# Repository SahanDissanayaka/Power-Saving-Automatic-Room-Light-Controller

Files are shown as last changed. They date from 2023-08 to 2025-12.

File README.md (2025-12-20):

# Power Saving Automatic Light Controller

## Project Overview
The Power Saving Automatic Light Controller is designed to automatically control lighting to conserve energy. This system uses motion detection to operate lights only when necessary, thus enhancing efficiency and reducing electricity consumption.

## Team Members
- **Sahan Dissanayaka**
- **Sadaru Liyanaarachchi**
- **Pasindu Nimsara**
- **Dilshan Nuwantha**

## Contents
1. [Specifications](#specifications)
2. [Circuit Design](#circuit-design)
3. [Enclosure Design](#enclosure-design)
4. [Budget Proposal](#budget-proposal)
5. [Finalized Product](#finalized-product)
6. [Contributions](#contributions)

## Specifications
### Transmitter Part

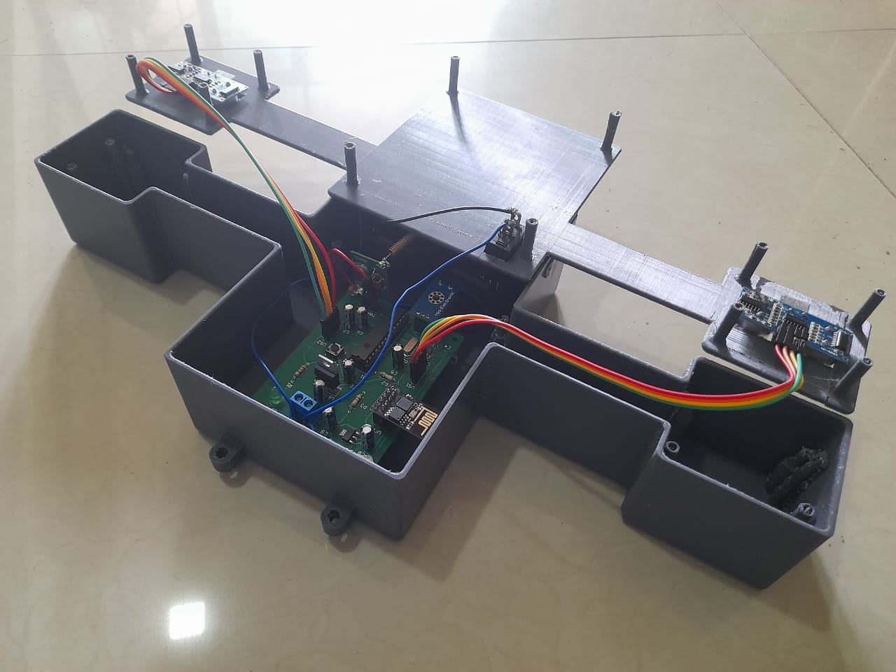
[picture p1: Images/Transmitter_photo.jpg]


- Controlled by ATMEGA328PU micro-controller
- Motion detection using two ultrasonic sensors
- Communication with receiver using 433MHz transmitter
- Wi-Fi updates via ESP8266 module
- Powered by two 3.7V rechargeable batteries

### Receiver Part

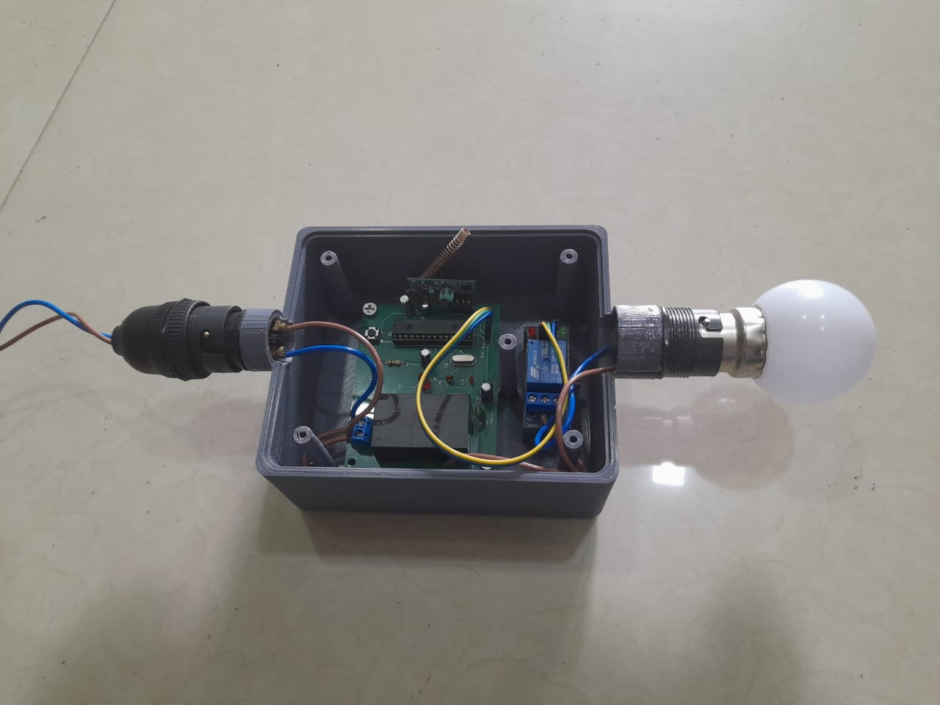
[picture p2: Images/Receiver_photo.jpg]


- Controlled by ATMEGA328PU micro-controller
- Communication with transmitter using 433MHz receiver
- Power supply: 230V AC to 5V DC step-down transformer

## Circuit Design
### Transmitter Side
- Ultrasonic sensors for motion detection
- 433 MHz transmitter for wireless communication
- ESP8266 wifi module for Wi-Fi connectivity

### Receiver Side
- 433 MHz receiver for wireless communication
- Step-down transformer for power supply

## Enclosure Design
### Transmitter Enclosure
- Designed for portability and durability
- Protects internal components from environmental factors

### Receiver Enclosure
- Designed for fixed installation
- Ensures safety and longevity of internal components

## Finalized Product
- **Transmitter Part**: Efficiently detects motion and transmits data wirelessly.
- **Receiver Part**: Receives data and controls lighting based on the received information.

## Thank You
Thank you for reviewing our project. We appreciate your interest and support.

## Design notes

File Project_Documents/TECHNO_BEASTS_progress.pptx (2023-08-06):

## Power Saving Automatic Light Controller

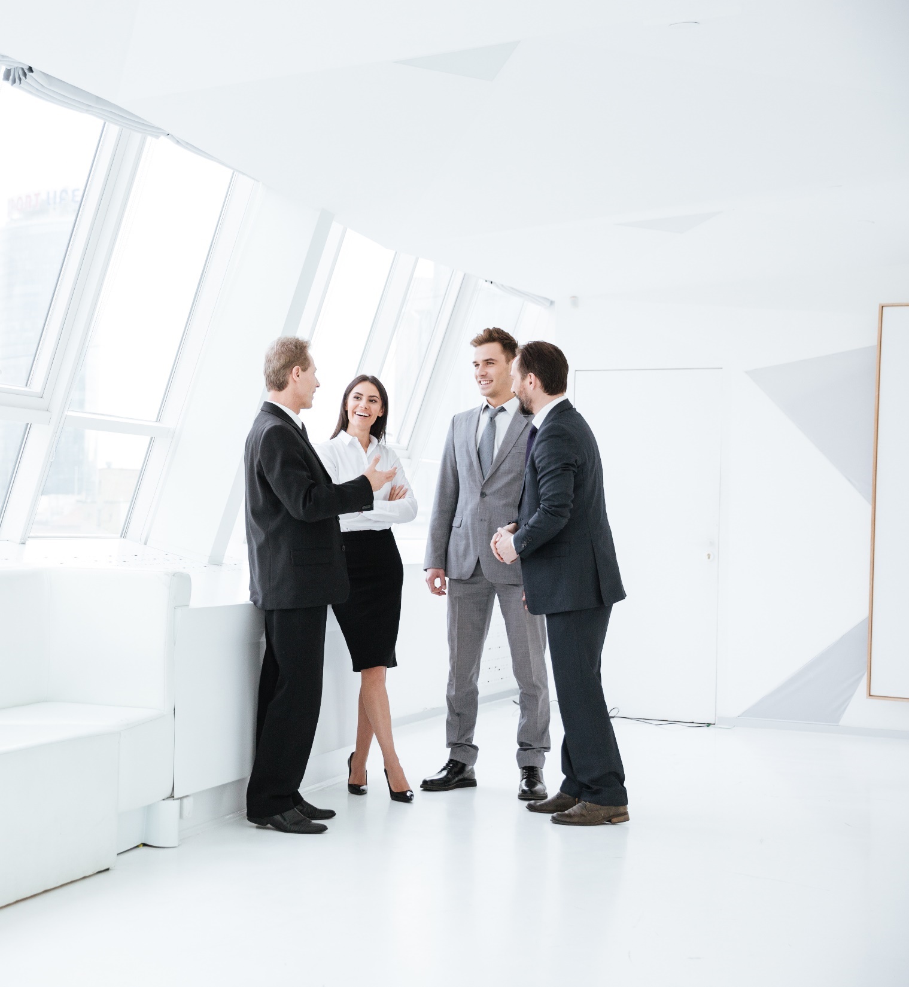
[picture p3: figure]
Group of people talking
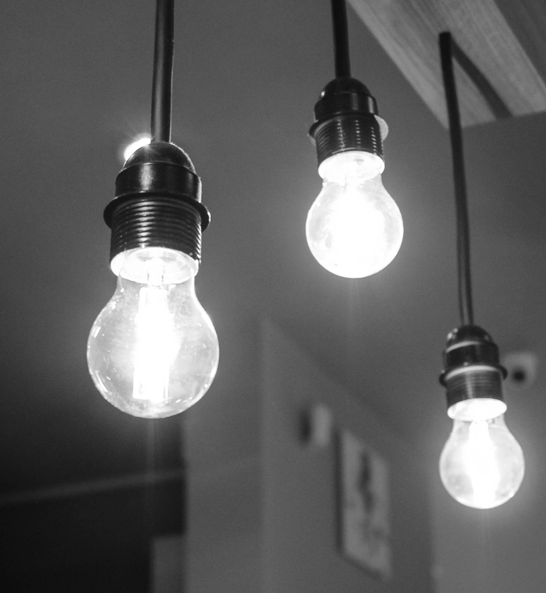
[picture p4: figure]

Team Techno beast

- 210141U – Dissanayaka D.M.S.P.
- 210341H – Liyanaarachchi L.A.S
- 210303U – Kulasingham P.N
- 210705E – Wickramasingha M.P.D.N

## Content

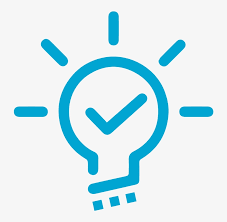
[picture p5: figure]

Problem & Solution
Problem
Survey Results
Solution
Technical Feasibility
Resource Requirements
Performance Targets
Technical Risks
Testing and Evaluation
Product Architecture
Sensor part
Light bulb part
Sketches
Initial Sketch
Finalized Sketch
Marketing & Sales
Marketing
Sales
After-sale Service
Bill of quantities
Summery of expenditure
Quantities

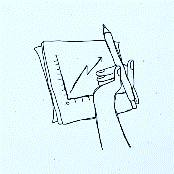
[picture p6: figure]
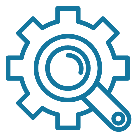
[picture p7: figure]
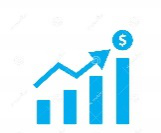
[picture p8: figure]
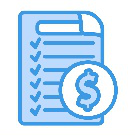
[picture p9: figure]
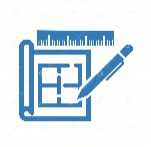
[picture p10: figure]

## Problem & Solution

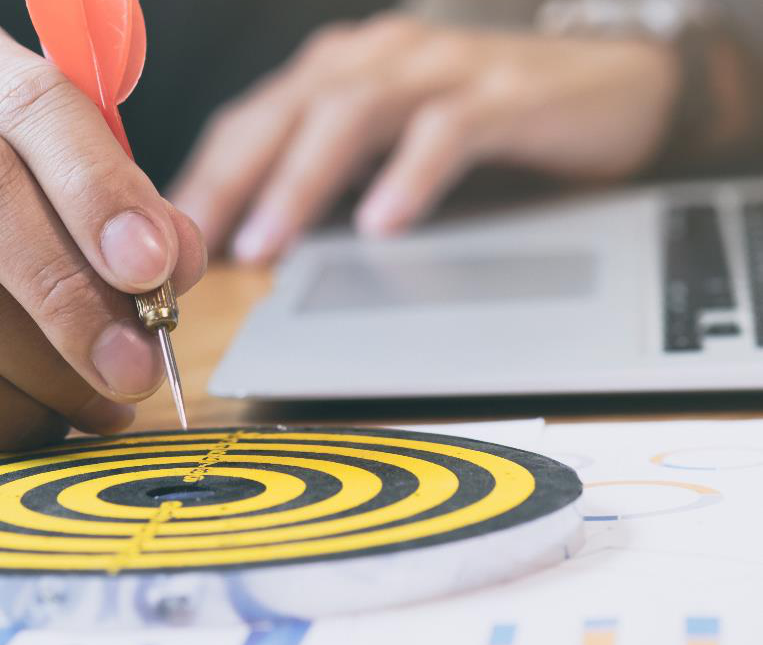
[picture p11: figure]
A picture containing object that represents mission, goal

- Do you forget to switch off the bulb when they are leaving the place?
- Have you any children or disable member in your family which can’t turn off lights.
- The development of this project is a timely and essential project with the potential to solve not only that but also extra too many problems.

## Survey Results

- We got 198 responses from the survey.
- We targeted a sample in society with all types of people covered.
- We could find many valuable facts and identify what people need.

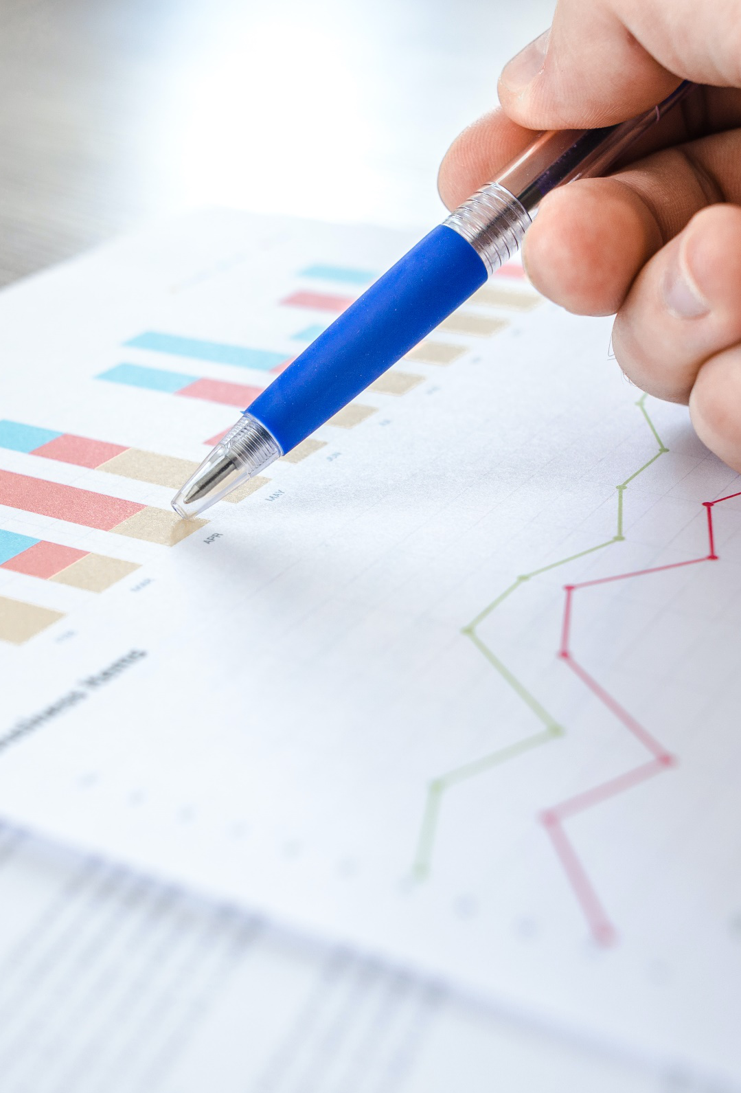
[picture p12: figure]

## Survey Results

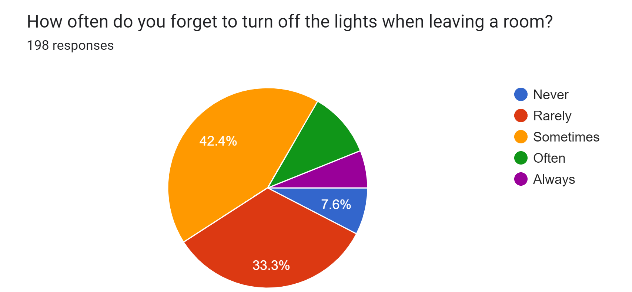
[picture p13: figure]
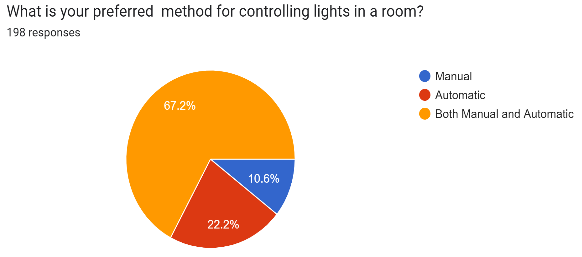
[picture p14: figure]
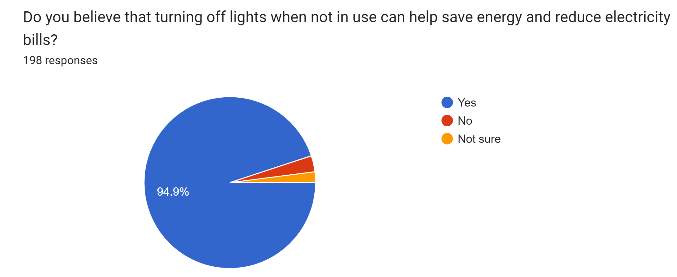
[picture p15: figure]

## Survey Results

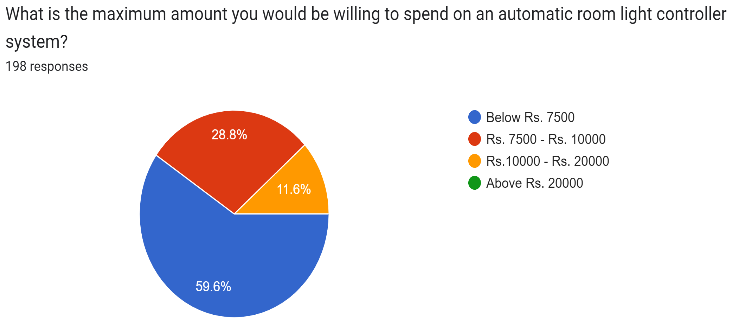
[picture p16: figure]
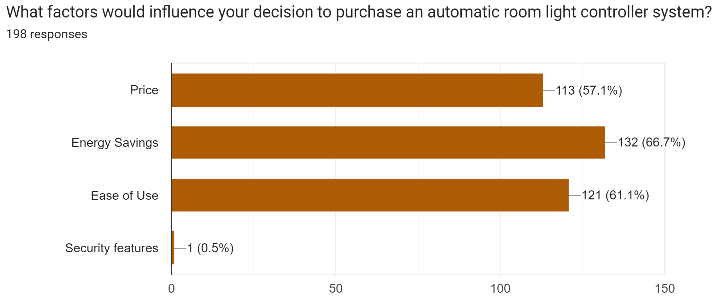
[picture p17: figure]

## Technical Feasibility

Resource Requirements

- Include light bulbs, sensors, PCBs, power-supplying methods, and transmitters.
- The software requirements include firmware for the microcontrollers, communication protocols.
- The software that we needed is Arduino, Solid Works, Altium, etc.

Performance Targets

- Based on industry standards.
- The system will be designed to turn on the lights automatically when someone enters the room and turn them off when they leave, thereby conserving energy.
- The main thing is when people enter the room more than one, the light will only be off if all of them left from the room.

## Technical Feasibility

Technical Risks

- mainly related to hardware and software compatibility.
- We have addressed these risks by carefully selecting the components and developing software components that are compatible with each other.
- tested the system thoroughly in a controlled environment and have identified and resolved any issues.

Testing and Evaluation

- Tested using a combination of manual testing and automated testing tools using simulations and hardware components.
- The tests will be conducted in a controlled environment simulating different scenarios and conditions.
- The evaluation criteria will be based on the system's energy efficiency, response time, reliability, and accuracy.

## Product Architecture

Power Supply (Battery)

7805 Regulator

input

Microprocessor

output

input

Ultrasonic

Transmitter

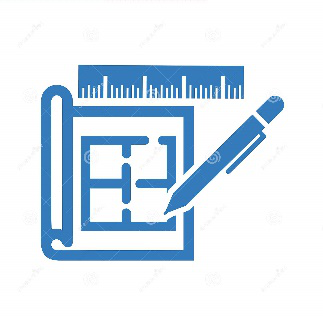
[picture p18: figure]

Receiver

Main Power 230V

Microprocessor

input

Relay Module

Hi-Link Transformer

input

output

Bulb

## Initial and Finalized Sketches

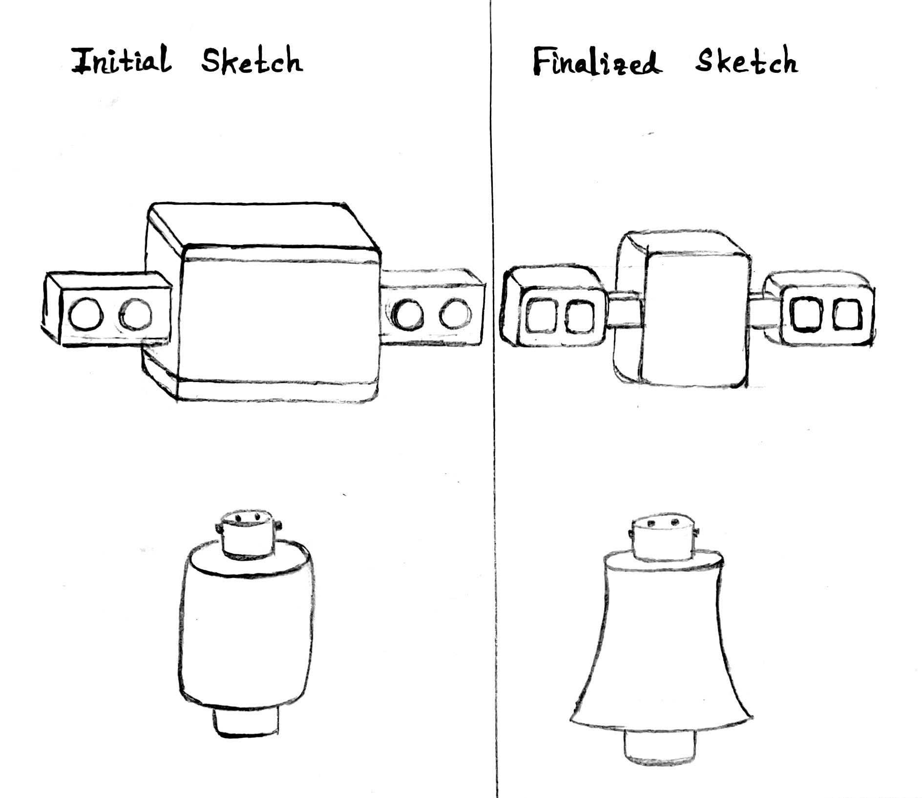
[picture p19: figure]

## Marketing, Sales, and After-Sale Service Considerations

- Marketing

- Mostly middle age people will be targeted because they are interested in technology and easy ways to do something.
- Use social media platforms and digital marketing strategies to reach a wider audience and it’s better to advertise on TV is useful because most people can be caught.
- Partner with home automation companies and energy-efficient solution providers to increase exposure and reach new customers.
- Attend trade shows and exhibitions to showcase the product and generate interest.

- Sales

- Develop a sales strategy to ensure the automatic light bulb system is priced competitively. Create a sales team to promote and sell the product to potential customers.
- Offer discounts or prizes to make the product more attractive.
- Provide incentives to retailers and distributors to promote the product.
- Develop a sales forecast to project revenue and sales targets. It is a back-office task but more important to succeed in the purpose.

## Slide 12

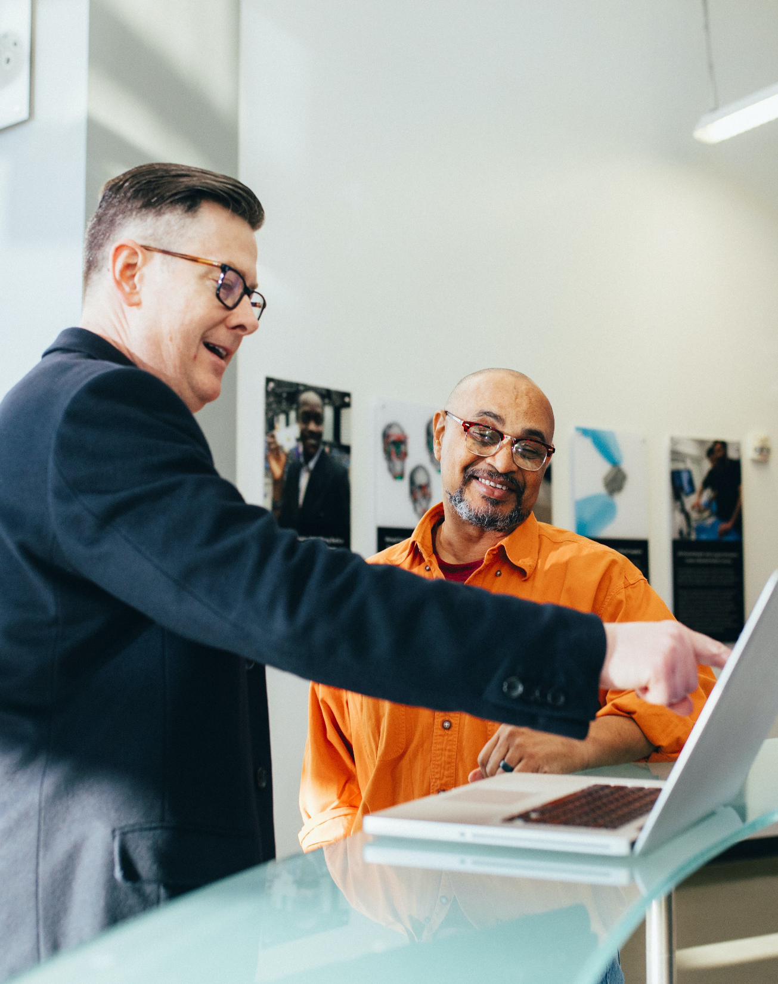
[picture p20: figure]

- After-Sale Service

- Offer a warranty and maintenance plan for the automatic light bulb system. But pay attention to the period and conditions.
- Provide customer support via email, phone, or online chat to answer questions and troubleshoot issues.
- Develop a customer feedback mechanism to monitor satisfaction levels and improve the product. I will be really important to the market also.
- Provide training and educational resources for customers to ensure they get the most out of the product.
- Develop a repair and replacement plan to address any issues that may arise.

## Bill of Quantities

Product | Price
Atmel ATMEGA328-PU microcontroller(2) | Rs. 2800.00
HC-SR04 4Pin Ultrasonic Sensor Module(2) | Rs. 640.00
433MHz Wireless RF Transmitter Receiver Module(1) | Rs. 340.00
5VDC 1 way 1 Channel Relay Module(1) | Rs. 180.00
L7805CV 5V Voltage Regulator(1) | Rs. 50.00
Tactile Push bottom 6×6×4 mm (2) | Rs. 20.00
16MHz Crystal Oscillator(2) | Rs. 80.00
220-ohm 2W resistor pack Carbon Film THT 5% (approx.5pcs)(1) | Rs. 60.00

Product | Price
10k ½ W Resistor Pack Carbon Film THT 5% (Approx.20pcs) | Rs.60.00
22pF Ceramic Capacitor THT(4) | Rs. 20.00
10uF 16V Electrolytic Capacitor THT(3) | Rs. 30.00
1nF 16V Electrolytic Capacitor THT(2) | Rs. 10.00
2-way Mini JST 2.0 PH Connector Wire Micro bit(2) | Rs. 40.00
Hi-Link HLK-5M05 220VAC to 5VDC 5W Step-Down Power Supply Module(1) | Rs. 1350.00
28-pin Normal IC Base 2.5 mm (HE0021)(2) | Rs. 40.00
433MHz Helical Antenna(2) | Rs. 230.00

Total | Rs. 5945.00

## Thank you!

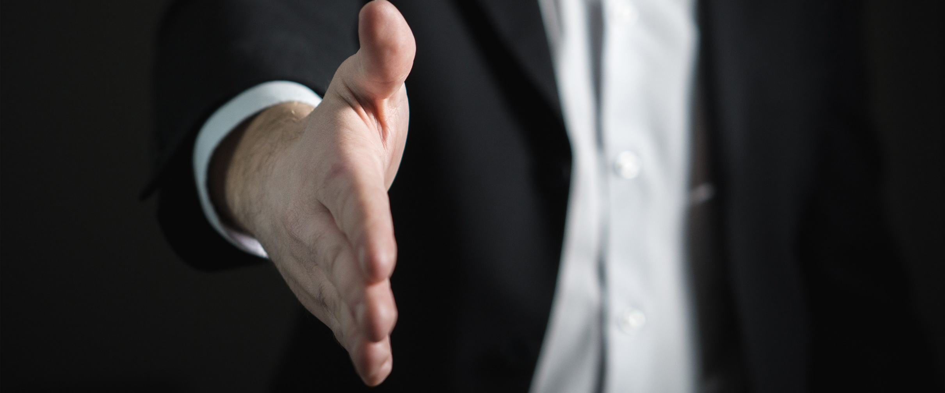
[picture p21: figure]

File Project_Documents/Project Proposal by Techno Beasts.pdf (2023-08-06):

# EN1190 Engineering Design Project

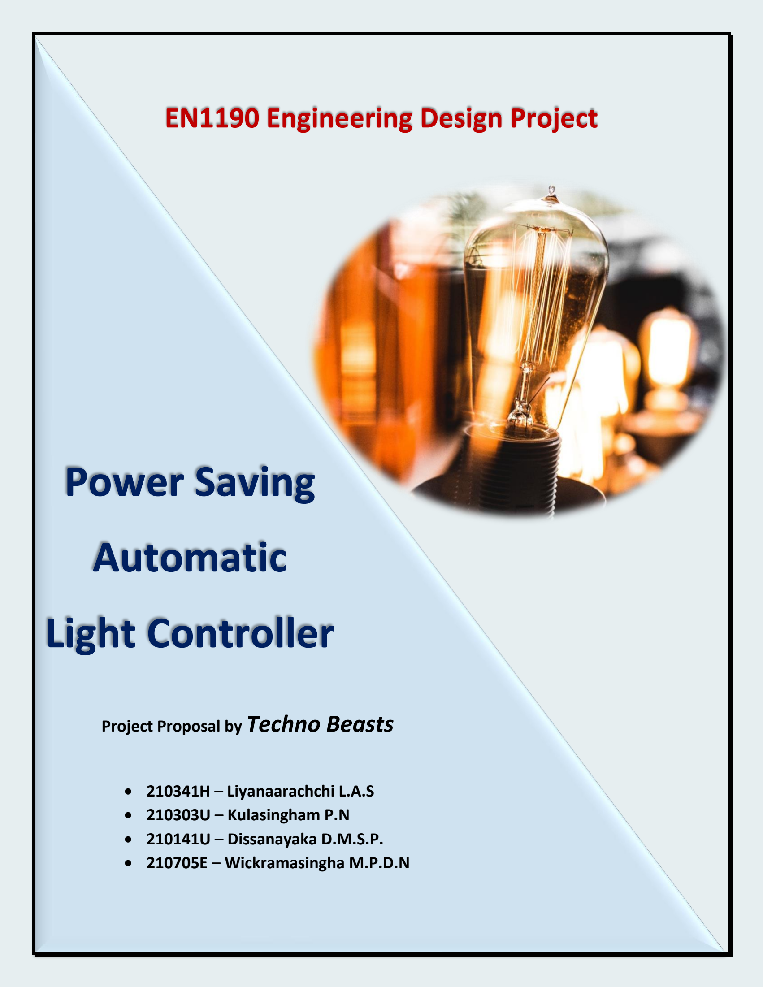
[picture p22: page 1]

Project Proposal by Techno Beasts

- 210341H – Liyanaarachchi L.A.S
- 210303U – Kulasingham P.N
- 210141U – Dissanayaka D.M.S.P.
- 210705E – Wickramasingha M.P.D.N

# Power Saving

# Automatic

# Light Controller

## Introduction

## Identified Problem

## Solutions

❖ In this project we mainly focus to build an automatic room light controller to save the power by counting the number of people who entering to the room and getting
out from the room. Also, we hope to bring some convenience to users by reducing their time they spend switching the ON and OFF bulb.

❖ Energy Waste: Traditional light switches can lead to unnecessary energy waste, as people often forget to turn off the lights when leaving a room. It can cause to increasing energy waste and electricity bills.
❖ Convenience: It might be inconvenient to have to manually turn lights on and off every time we enter or leave a place.
❖ Accessibility: Disabled people may face challenges in accessing and operating light switches, which can limit their independence and make it difficult to navigate the surroundings.
❖ Safety: Forgetting to turn off a light before leaving a room can pose safety risks, such as the risk of fire hazards or damage to property.

❖ Energy Efficiency: Our automatic room light controller can help reduce energy waste by turning off the lights when no one is present in the room. This can lead to a decrease in energy consumption and lower electricity bills.
❖ Convenience: By automatically turning on the lights when someone enters the room, automated light controller may give a more smooth and convenient lighting experience, removing the need for manual switches.
❖ Accessibility: Our light controller can help to increase accessibility for disabled people who may have difficulties with accessing or manipulating light switches. This project can make it easy for everyone to use the lighting by automating the process of turning lights on and off.
❖ Safety: Light controller can help to protect the property without any damage by turning off the lights automatically when no one is in the room.
❖ Cost Savings: Our design can help to reduce electricity bills by lowering energy consumption. It helps people to stabilize financial. This can lead to long-term cost savings for homeowners or businesses.

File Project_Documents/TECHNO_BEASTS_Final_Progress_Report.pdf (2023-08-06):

## Department of Electronic and Telecommunication Engineering University of Moratuwa EN1190 – Engineering Design Project

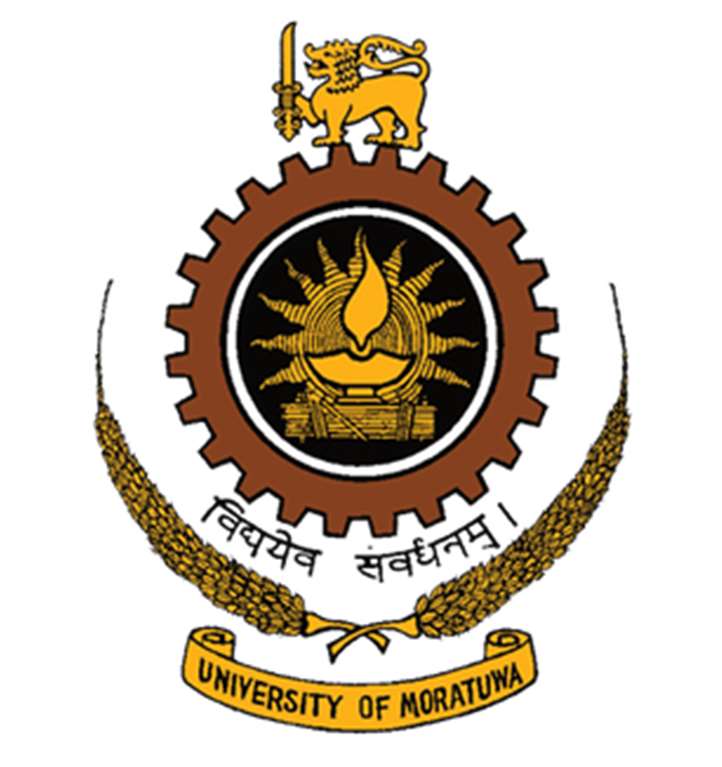
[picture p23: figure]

### Power Saving Automatic Light Controller

Group Members
- 210141U – Dissanayaka D.M.S.P.
- 210341H – Liyanaarachchi L.A.S
- 210303U – Kulasingham P.N
- 210705E – Wickramasingha M.P.D.N

1

## Table of Contents

2

## Abstract

Our design, a power-saving automatic light controller, is a device that automatically turns lights on and off based on the presence or absence of people in a room or area. The controller uses sensors such as ultrasonic sensors to detect human movements and switch the lights on and off accordingly. By using this type of controller, energy consumption is reduced since lights are only activated when needed. Additionally, the controller can be programmed to adjust the brightness level of the lights, further reducing energy consumption. The power-saving automatic light controller is a practical and cost-effective solution for reducing energy consumption and improving the efficiency of lighting systems and which is more helpful for disabled people. In this report, we consider what people think about our product through the survey. Furthermore, the technical feasibility and budget of the product are also included in this report.

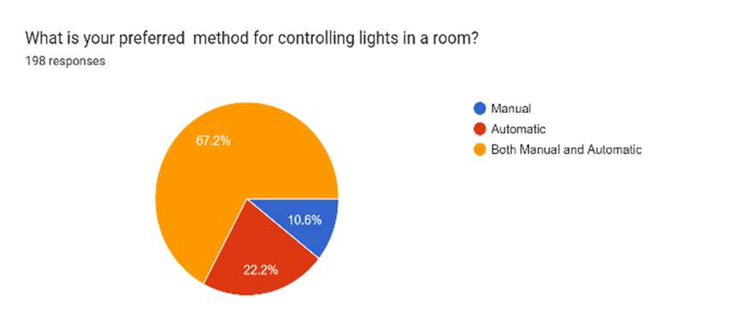
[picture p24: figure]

3

## Problem & Solution

In day-to-day life, most people forget to switch off the bulb when they are leaving the place. It may cause energy waste. Therefore, electricity consumption will be increased. In these days, if electricity consumption is increased then the electricity bill will be increased. Our income got wasted because of that. By implementing an automated lighting solution that turns off lights when a room is unoccupied, we can reduce energy waste and promote a more sustainable future. Hence, we should save energy. For that at least we can switch off the bulbs when we leave the place. So, we can introduce an automatic system for switching off the bulbs. And, if we forget to turn off the light bulbs then it may cause safety risks such as fire hazards or property damage.
In our society, we meet disabled people. They are suffering because they cannot do their work individually. As an example, people who are using wheelchairs cannot switch on the lights in the room without others' help. Such as most disabled people suffer from these stuffs. So, these people face different kinds of problems such as accessing and operating light switches. So, we are thinking to introduce an automatic system for lighting the bulbs. It helps to increase disabled people’s independence. Therefore, they can enter a room without others' help.

## Survey Summary

We did a small survey on our project. Some of the responses are shown below.
Most responders sometimes forget to turn off the lights when they leave the room. The least number of responders turn off the lights when leaving a room.

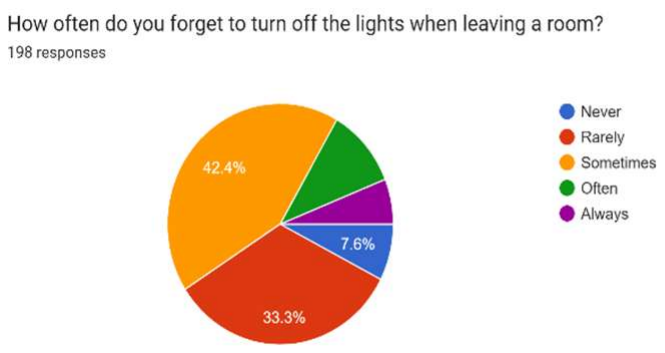
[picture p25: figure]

Most people like to control lights in both manual and automatic manners. Minimum responders prefer to turn on and off lights manually. So, this will help to improve our product in both manual and automatic.
When individuals with disabilities or children use this product, we can guarantee their safety and they can increase their independence. As the responses of the responders all of them said that disabled people can improve their safety.

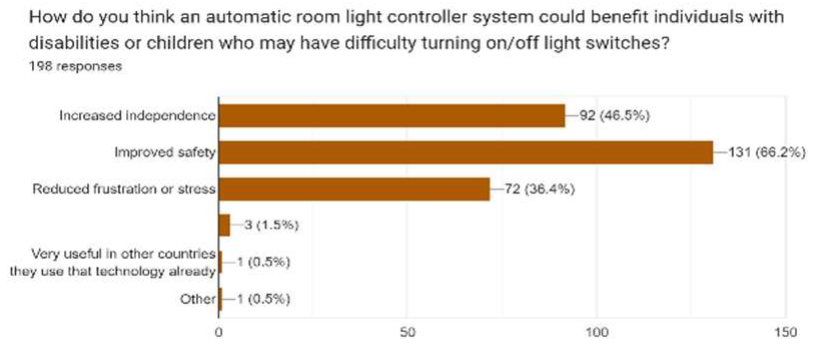
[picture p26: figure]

Most of the respondents prefer to buy our product by spending below Rs. 7500. And 57 responders like to spend between Rs. 7500 – Rs. 10000 to buy this product. Furthermore, some of them also prefer to spend between Rs.1000-Rs.2000 for this.

4

## Technical Feasibility

## Resource Requirements

The hardware requirements for the system include light bulbs, sensors, PCBs, power-supplying methods, and transmitters. These components are readily available in the market and can be created and designed. The software requirements include firmware for the microcontrollers and communication protocols. The software that we needed is Arduino, Solid Works, Altium, etc.

## Performance Targets

The system's performance targets are based on industry standards and there are no mistakes. The system will be designed to turn on the lights automatically when someone enters the room and turn them off when they leave, thereby conserving energy. The most important thing is when people enter the room more than one, the light will only be off if all of them are left from the room. The system will also have a user-friendly control system because of the manual and automatic systems.

## Technical Risks

The technical risks associated with the project are mainly related to hardware and software compatibility. We have addressed these risks by carefully selecting the components and developing software components that are compatible with each other. We have also tested the system thoroughly in a controlled environment and have identified and resolved any issues that arose during testing.

## Testing and Evaluation

The system will be tested and evaluated using a combination of manual testing and automated testing tools using simulations and hardware components. The tests will be conducted in a controlled environment simulating different scenarios and conditions, such as varying ambient light levels and occupancy patterns. The evaluation criteria will be based on the system's energy efficiency, response time, reliability, and accuracy. The test results will refine the system design and improve its performance.

## Product Architecture

input; output

## PCB Designs

## Transmitter Side PCB


6

## Receiver Side PCB


7

## Enclosure Designs

## Transmitter Side Enclosure


8

## Receiver Side Enclosure


9

## Web Site

## https://technobeasts.42web.io

## Finalized Product


10

## Transmitter

## Receiver

11

## Marketing, Sales, and After-Sale Service Considerations

## Marketing:

Developing a comprehensive marketing plan to promote the automatic light bulb system:
a. Identify the target audience for the product and tailor marketing efforts accordingly. Mostly middle-aged people will be targeted because they are interested in technology and easy ways to do something.
b. Using social media platforms and digital marketing strategies to reach a wider audience and it’s better to advertise on TV is useful because most people can be caught by it as well as social media.
c. Partner with home automation companies and energy-efficient solution providers to increase exposure and reach new customers. Energy efficiency is another opportunity for succeed our product. Most people will be attracted to it because of the energy crisis.
d. Attending trade shows and exhibitions to showcase the product and generate interest.

## Sales:

1. Develop a sales strategy to ensure the automatic light bulb system is priced competitively. With our survey, we found it is okay to price range above Rs.5000.00 because practically the product cost is already above Rs.5000.00.
2. Create a sales team to promote and sell the product to potential customers.
3. Offer discounts or prices to make the product more attractive.
4. Provide incentives to retailers and distributors to promote the product.
5. Develop a sales forecast to project revenue and sales targets. It is a back-office task but more important to succeed in the purpose.

## After-Sale Service:

### 1. Offer a warranty and maintenance plan for the automatic light bulb system. But pay

attention to the period and conditions.

### 2. Provide customer support via email, phone, or online chat to answer questions

and troubleshoot issues.

### 3. Develop a customer feedback mechanism to monitor satisfaction levels and improve

the product. It will be important to the market also.
4. Provide training and educational resources for customers to ensure they get the most out of the product.
5. Develop a repair and replacement plan to address any issues that may arise.
By considering Marketing, Sales, and After-Sale Service considerations, we can ensure the success of the automatic light bulb system project by reaching a wide audience, generating sales, and providing excellent customer support.

12

## Bill of quantities

Product | Quantity | Price of one quantity | Price
Atmel ATMEGA328-PU microcontroller | 2 | Rs. 1400.00 | Rs. 2800.00
HC-SR04 4Pin Ultrasonic Sensor Module | 2 | Rs. 320.00 | Rs. 640.00
433MHz Wireless RF Transmitter Receiver Module | 1 | Rs. 340.00 | Rs. 340.00
5VDC 1 way 1 Channel Relay Module | 1 | Rs. 180.00 | Rs. 180.00
L7805CV 5V Voltage Regulator | 1 | Rs. 50.00 | Rs. 50.00
Tactile Push bottom 6 × 6 × 4 mm | 2 | Rs. 10.00 | Rs. 20.00
16MHz Crystal Oscillator | 2 | Rs. 40.00 | Rs. 80.00
220-ohm 2W resistor pack Carbon Film THT 5% (approx.5pcs) | 1 | Rs. 60.00 | Rs. 60.00
10k ½ W Resistor Pack Carbon Film THT 5% (Approx.20pcs) | 1 | Rs. 60.00 | Rs. 60.00
22pF Ceramic Capacitor THT | 4 | Rs. 5.00 | Rs. 20.00
10uF 16V Electrolytic Capacitor THT | 3 | Rs. 10.00 | Rs. 30.00
1nF 16V Electrolytic Capacitor THT | 2 | Rs. 5.00 | Rs. 10.00
2-way Mini JST 2.0 PH Connector Wire Micro bit | 2 | Rs. 20.00 | Rs. 40.00
Hi-Link HLK-5M05 220VAC to 5VDC 5W Step-Down Power Supply Module | 1 | Rs. 1350.00 | Rs. 1350.00
28-pin Normal IC Base 2.5 mm (HE0021) | 2 | Rs. 20.00 | Rs. 40.00
433MHz Helical Antenna | 2 | Rs. 115.00 | Rs. 230.00
ESP8266 WIFI Module | 1 | Rs. 450.00 | Rs. 450.00
Voltage Senser | 1 | Rs.130.00 | Rs.130.00
PCB (Transmitter Side) | 1 | Rs. 230.00 | Rs. 230.00
PCB (Receiver Side) | 1 | Rs. 230.00 | Rs. 230.00
Enclosure (Transmitter Side) | 1 | Rs. 15000.00 | Rs. 15000.00
Enclosure (Receiver Side) | 1 | Rs. 5000.00 | Rs. 5000.00
Total | | | Rs. 26990.00

13

## Task Allocation

The workload of the project is equally distributed among all the group members.

210141U – Dissanayaka D.M.S.P.
- Transmitter Part PCB
- Coding
- Web site developing

210303U – Kulasingham P.N.
- Receiver Part PCB
- Coding

210341H – Liyanaarachchi L.A.S.
- Transmitter Part Enclosure
- Soldering

210705E – Wickramasingha M.P.D.N.
- Receiver Part Enclosure
- Soldering

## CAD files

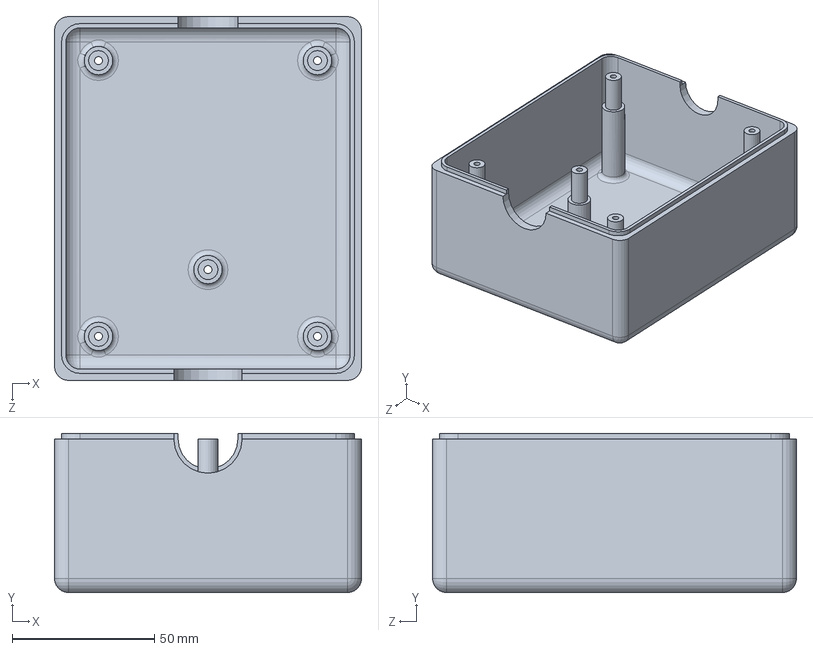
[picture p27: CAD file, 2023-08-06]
Receiver_enclosure/part02.SLDPRT
108.0 x 56.0 x 128.0 mm

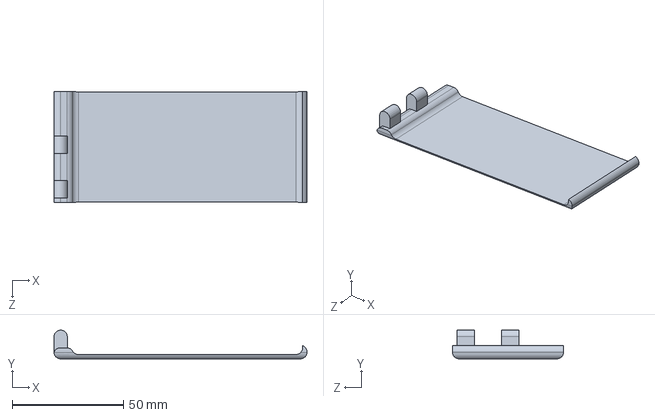
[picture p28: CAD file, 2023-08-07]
Transmitter_enclosure/newlid2.SLDPRT
113.9 x 13.0 x 50.0 mm

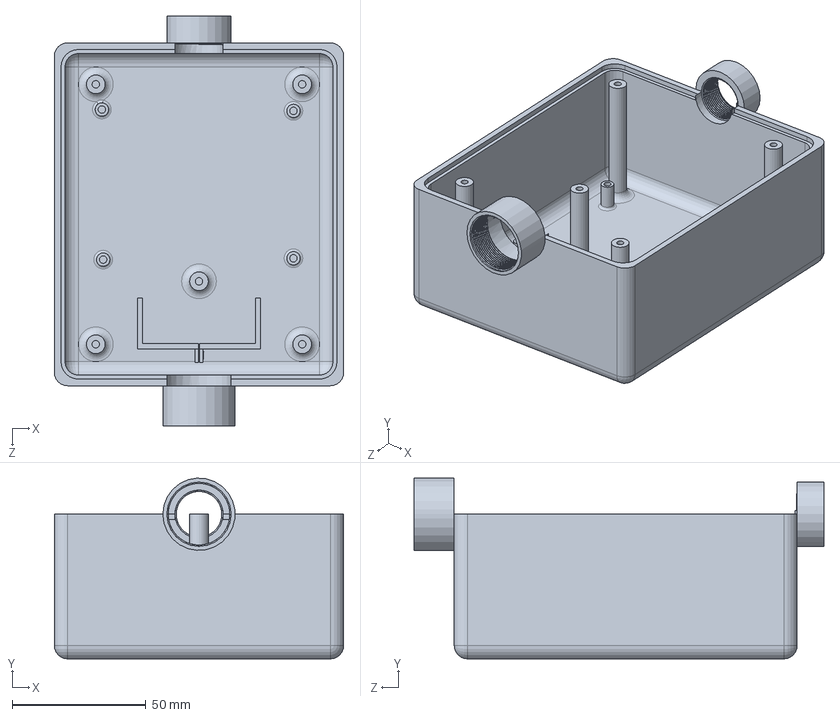
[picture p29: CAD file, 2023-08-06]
Receiver_enclosure/part01.SLDPRT
108.0 x 67.5 x 153.0 mm

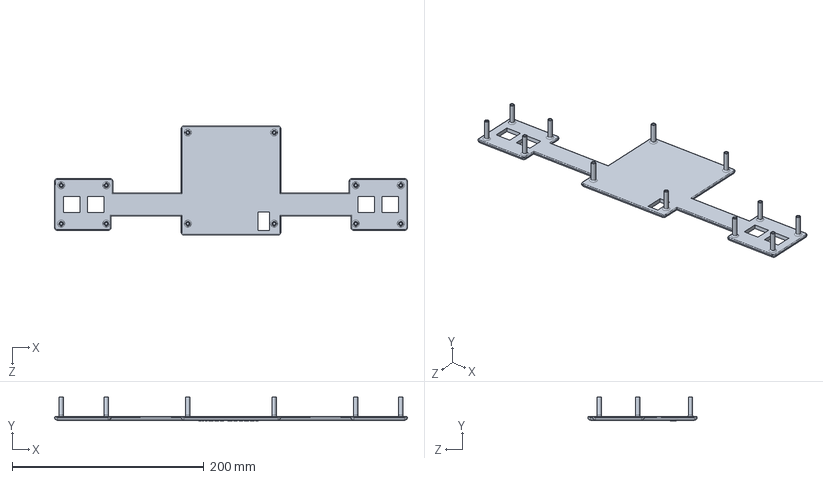
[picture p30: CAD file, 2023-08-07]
Transmitter_enclosure/newlid1.SLDPRT
368.0 x 24.5 x 114.0 mm

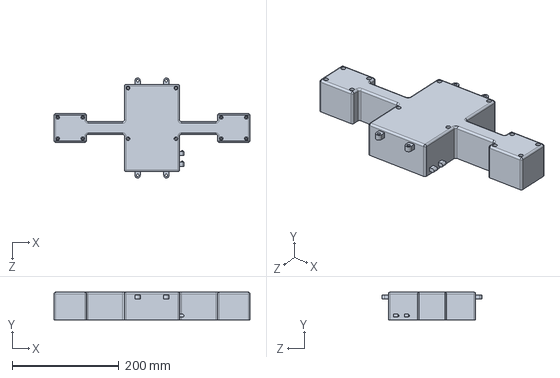
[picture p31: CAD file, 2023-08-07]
Transmitter_enclosure/newenclosureSLDPRT.SLDPRT
368.0 x 52.0 x 188.0 mm

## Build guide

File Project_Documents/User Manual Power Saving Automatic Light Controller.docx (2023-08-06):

Power Saving Automatic Light Controller

User Manual

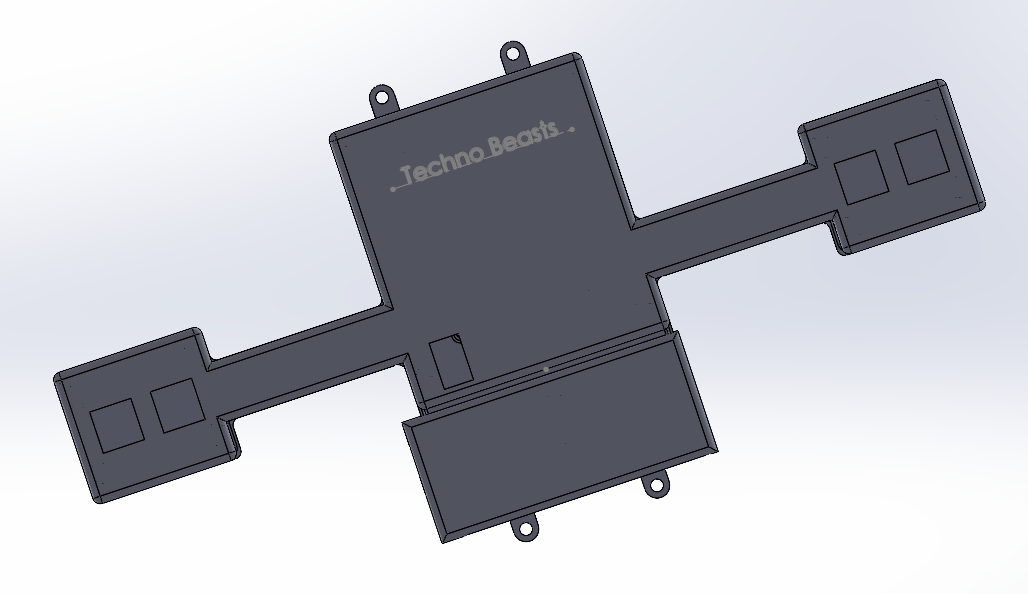
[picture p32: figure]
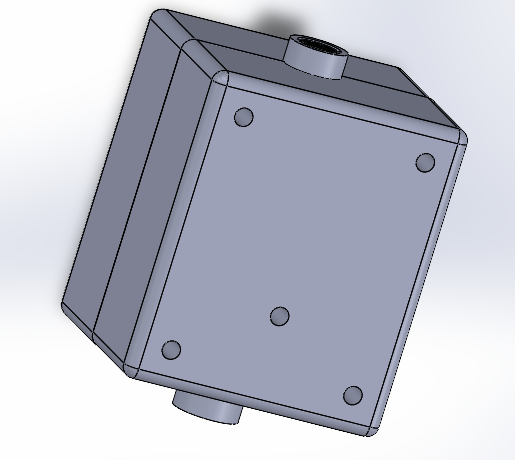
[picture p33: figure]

Techno Beasts

Welcome to the user manual for the Power-Saving Automatic Room Light Controller. This device is designed to automatically control room lights based on occupancy, helping you save energy and reduce electricity bills. The two ultrasonic sensors detect movement within the room and trigger the lights to turn on or off accordingly.

Safety Instructions

- Read this manual carefully before installation and operation.
- Ensure the power supply is disconnected before handling the device.
- Avoid exposing the sensors to direct sunlight or strong artificial light, as it may affect their performance.
- Keep the device away from water or other liquids to prevent electrical hazards.
- Do not tamper with the internal components; contact authorized service personnel for any repairs.

Product Overview

The Power-Saving Automatic Room Light Controller consists of the following components:

- Two Ultrasonic Sensors: Detect movement and occupancy within the room.

- Microcontroller Unit (MCU): Processes sensor inputs and controls the room lights.

- Relay Module: Controls the electrical connection between the light source and the power supply.

- Power Supply: Provides the required voltage for the device to operate.

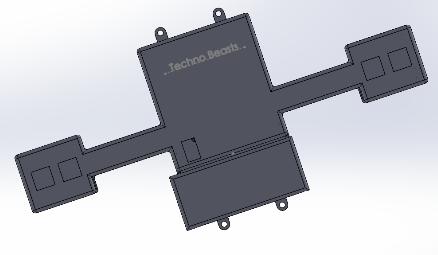
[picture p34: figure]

Installation Guide

Part 1: Transmitter Installation

Step 1: Prepare the Transmitter Unit

- Unbox the transmitter unit.
- Fully charge the rechargeable batteries using the provided charging cable and a suitable USB power source.

Step 2: Mounting the Transmitter Unit

- Choose a suitable location on the wall or door where you want to install the transmitter unit. Make sure it has a clear line of sight to the area you want to monitor.
- Use screws or adhesive tape to securely attach the transmitter unit to the chosen surface. Ensure that the sensors face the area you wish to monitor.

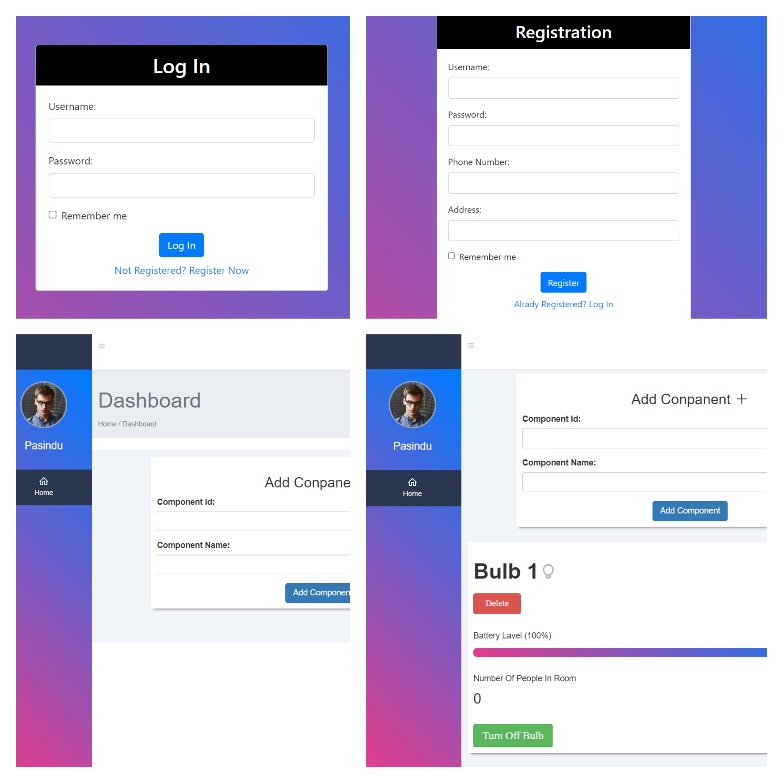
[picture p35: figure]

Step 3: Connecting to the Web Interface

- Turn on the transmitter unit using the power switch if available. The sensors will now start detecting motion.
- Connect your computer or smartphone to the Wi-Fi network.
- Open a web browser and enter the IP address or domain name (https://technobeastsdata.000webhostapp.com/login.php) then register to the site. After you log in enter the component ID which we are given and click Add Component button.
- Then you can see the battery level and number of people who are in the room.

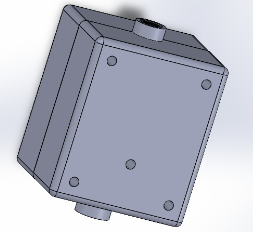
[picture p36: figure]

Part 2: Receiver Installation

Step 1: Prepare the Receiver Unit

- Unbox the receiver unit and ensure all components are included: a suitable holder for installation.
- Check that the main power supply (230V) is available and easily accessible at the chosen installation location.

Step 2: Mounting the Receiver Unit

- Mount the receiver module inside the provided holder, making sure it is securely fixed.
- Connect the receiver unit to the main power supply (230V) using the provided power cord. Ensure proper electrical connections and safety.

Step 3: Pairing the Transmitter and Receiver

- Turn on the receiver unit by plugging it into the main power supply.
- On the web interface or application, initiate the pairing process to connect the transmitter and receiver units.
- Follow the on-screen instructions to establish a secure connection between the two units.

Step 4: Testing the Automatic Room Light Controller

- With the receiver unit powered on and the transmitter unit installed, walk into the monitored area to test the motion detection.
- Verify that the light turns on when motion is detected and turns off when the area is empty.

Troubleshooting

If you encounter any issues with the automatic room light controller, refer to the following troubleshooting guide:

- Issue: Lights do not turn on.
- Check the power supply and ensure it is connected and functioning correctly.
- Check whether the batteries are dead or not. If batteries are dead then you can charge the batteries or replace the battery.

Maintenance

To ensure optimal performance, perform the following maintenance tasks:

- Regularly clean the sensors' lenses to remove dust or dirt that may affect their sensitivity.

- Check all wiring connections periodically for signs of damage or loose connections.

Technical Specifications

- Operating Voltage: 7.4V (7V-12V)
- Installation: Wall mounted
- Sensor Type: Ultrasonic
- Detection Range: 4cm – 40m

Warranty and Support

The Power-Saving Automatic Room Light Controller comes with a year warranty. For any technical assistance or inquiries, please contact our customer support team.

Contact Details:

- +94 77 043 2076 – Pasindu
- +94 71 677 3542- Sandaru

Congratulations! You have successfully installed and set up the Power-Saving Automatic Room Light Controller. Enjoy the convenience of automatic lighting control and the energy savings it brings. If you have any further questions or feedback, do not hesitate to contact our support team. Thank you for choosing our product!

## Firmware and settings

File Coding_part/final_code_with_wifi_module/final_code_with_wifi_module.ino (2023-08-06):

//include NewPing library to get distance using ultrasonic sensor
#include <NewPing.h>

// include RadioHead Amplitude Shift Keying Library
#include <VirtualWire.h>

// Include dependant SPI Library
#include <SPI.h>

// Create Amplitude Shift Keying Object



#define ECHO_PIN1 8
#define ECHO_PIN2 11
#define TRIG_PIN1 9
#define TRIG_PIN2 10

int num_of_persons = 0;
int check1 = 0;
int check2 = 0;
bool going_inside = false;
bool going_outside = false;

NewPing Sensor1(TRIG_PIN1, ECHO_PIN1, 2000);
NewPing Sensor2(TRIG_PIN2, ECHO_PIN2, 2000);

unsigned int dis_1;
unsigned int dis_2;

double get_battery_level() {
  // put your main code here, to run repeatedly:
  int volt = analogRead(A0);
  double voltage = map(volt, 0, 1023, 0, 2500);

  voltage = voltage/7.4;
  return voltage;
}


#include <SoftwareSerial.h>
#define RX 2
#define TX 3
String AP = "SLT-4G-74C6C8";       // AP NAME
String PASS = "7K7743775D"; // AP PASSWORD
String API = "tPmAT5Ab3j7F9";   // Write API KEY
String HOST = "192.168.1.240";
String PORT = "80";

int countTrueCommand;
int countTimeCommand; 
boolean found = false; 

SoftwareSerial esp8266(RX,TX); 


int compId=102;



void setup() {
  Serial.begin(9600);
  esp8266.begin(115200);
  sendCommand("AT", 5, "OK");
  sendCommand("AT+CWMODE=1", 5, "OK");
  sendCommand("AT+CWJAP=\"" + AP + "\",\"" + PASS + "\"", 20, "OK");
  

  vw_set_tx_pin(12); // Set the pin used for transmitting data
  vw_setup(2000);                   // Bits per second (baud rate)
  
  pinMode(ECHO_PIN1, INPUT);
  pinMode(ECHO_PIN2, INPUT);
  pinMode(TRIG_PIN1, OUTPUT);
  pinMode(TRIG_PIN2, OUTPUT);

  
 

  

}

int counter=0;

void loop() {
  
  counter++;
  if(counter==5){
    sendData();
    counter=0;
  }



  unsigned long start_time = millis();


  while (millis() - start_time <= 1000) {

    if (check1 != 1) {
      unsigned int dis = 0;
      
      for (int i = 0; i <= 5; i++) {
        dis = dis + Sensor1.ping_cm();
        
      }
      dis_1 = dis / 3;
      

      if (dis_1 < 70 ) {
        if (check2 == 1) {
          going_outside = true;
          check2 = 0;
        } else {
          check1 = 1;
          
        }

      }
    }

    if (check2 != 1) {
      unsigned int dis = 0;
      
      for (int i = 0; i <= 5; i++) {
        dis = dis + Sensor2.ping_cm();
        
      }
      dis_2 = dis / 3;

      if (dis_2 < 70) {
        if (check1 == 1) {
          going_inside = true;
          check1 = 0;
        } else {
          check2 = 1;
          
        }
      }
    }
  }

  if (going_inside && !going_outside) {
    num_of_persons ++;
    going_inside = false;
  } else if (going_outside && !going_inside) {
    if(num_of_persons > 0){num_of_persons--;}
    else{num_of_persons = 0;}
    going_outside = false;
  }

  Serial.println(num_of_persons);
  Serial.println(get_battery_level());
  

  going_inside = false;
  going_outside = false;
  check1 = 0; check2 = 0;

  if (num_of_persons > 0) {
    sendRadioData("1",1);
  }
  else {
    sendRadioData("0",1);
  }
}

void sendRadioData(const uint8_t* data, uint8_t len) {
  vw_send(data, len);
  vw_wait_tx(); // Wait until the whole message is gone
}



void sendData() {
 
  String num_people = String(num_of_persons);
  String battery_level = String(get_battery_level());
  String comp_id = String(compId);
  String getData = "GET /technoBeasts/postData/postEspData.php?method=data&api_key=tPmAT5Ab3j7F9&num_people=" + num_people + "&battery_level=" + battery_level + "&comp_id=" + comp_id;
  
  // Add the necessary headers
  String headers = "Host: " + HOST + "\r\n" +
                  "Connection: close\r\n" +  // Close the connection after the request is complete
                  "User-Agent: Arduino/1.0\r\n";  // You can specify your desired user agent

  int headersLength = headers.length();
  int requestLength = getData.length() + headersLength + 2; // Add 2 for the additional \r\n at the end

  sendCommand("AT+CIPMUX=1", 1, "OK");
  sendCommand("AT+CIPSTART=0,\"TCP\",\"" + HOST + "\"," + PORT, 1, "OK");
  sendCommand("AT+CIPSEND=0," + String(requestLength), 1, ">");

  esp8266.print(getData); // Send the request line
  esp8266.print("\r\n"); // New line after the request line
  esp8266.print(headers); // Send the headers
  esp8266.print("\r\n"); // New line after the headers

  delay(500); 
  countTrueCommand++;
  // sendCommand("AT+CIPCLOSE=0", 0.5, "OK");
}



void sendCommand(String command, int maxTime, char readReplay[]) {
  Serial.print(countTrueCommand);
  Serial.print(". at command => ");
  Serial.print(command);
  Serial.print(" ");
  while(countTimeCommand < (maxTime*1))
  {
    esp8266.println(command);//at+cipsend
    if(esp8266.find(readReplay))//ok
    {
      found = true;
      break;
    }
  
    countTimeCommand++;
  }
  
  if(found == true)
  {
    Serial.println("OYI");
    countTrueCommand++;
    countTimeCommand = 0;
  }
  
  if(found == false)
  {
    Serial.println("Fail");
    countTrueCommand = 0;
    countTimeCommand = 0;
  }
  
  found = false;
 }


 

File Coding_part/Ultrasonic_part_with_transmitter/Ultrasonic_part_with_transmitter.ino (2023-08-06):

//include NewPing library to get distance using ultrasonic sensor
#include <NewPing.h>

// include RadioHead Amplitude Shift Keying Library
#include <RH_ASK.h>

// Include dependant SPI Library
#include <SPI.h>

// Create Amplitude Shift Keying Object
RH_ASK rf_driver;

#define ECHO_PIN1 8
#define ECHO_PIN2 11
#define TRIG_PIN1 9
#define TRIG_PIN2 10

int num_of_persons = 0;
int check1 = 0;
int check2 = 0;
bool going_inside = false;
bool going_outside = false;

NewPing Sensor1(TRIG_PIN1,ECHO_PIN1,2000);
NewPing Sensor2(TRIG_PIN2,ECHO_PIN2,2000);

unsigned int dis_1;
unsigned int dis_2;

void get_battery_level(){
  // put your main code here, to run repeatedly:
  int volt = analogRead(A0);
  double voltage = map(volt, 0, 1023, 0, 2500);

  voltage /= 100;
  return voltage;
  }
  
void setup() {
  pinMode(ECHO_PIN1, INPUT);
  pinMode(ECHO_PIN2, INPUT);
  pinMode(TRIG_PIN1, OUTPUT);
  pinMode(TRIG_PIN2, OUTPUT);
  Serial.begin(9600);
  rf_driver.init();

}


void loop() {

  unsigned long start_time = millis();
 

  while (millis()- start_time <= 1000){

    if (check1 != 1){
      unsigned int dis=0;
      //Serial.print("dis1");Serial.print(" ");
      for (int i=0;i<=5;i++){
        dis = dis + Sensor1.ping_cm();
        //Serial.print(" ");Serial.print(dis);Serial.print(" ");
        }
       dis_1 = dis/3;
       //Serial.print(dis_1);

    if (dis_1 < 70 ) {
      if (check2 == 1) {
        going_outside = true;
        check2 = 0;
      } else {
        check1 = 1;
        //delay(200);
      }
  
    }
    }
    
    if (check2 != 1){
      unsigned int dis = 0;
      //Serial.print("dis2");Serial.print(" ");
      for (int i=0;i<=5;i++){
        dis = dis + Sensor2.ping_cm();
        //Serial.print(dis);Serial.print(" ");
        }
      dis_2 = dis/3;
      
      //Serial.println(dis_2);
    if (dis_2 < 70) {
      if (check1 == 1) {
        going_inside = true;
        check1 = 0;
      } else {
        check2 = 1;
        //delay(200);
      }
    }
      }
    }

  if (going_inside && !going_outside){
    num_of_persons ++;
    going_inside = false;
    }else if (going_outside && !going_inside){
      num_of_persons--;
      going_outside = false;
      }
          
  Serial.println(num_of_persons);
//  Serial.print(" ");
//  Serial.print(check1);Serial.print(" ");
//  Serial.println(check2);
  
  going_inside = false;
  going_outside = false;
  check1 = 0;check2 = 0;
  
  const char *msg;
  if (num_of_persons > 0){msg = "1";}
  else{msg = "0";}
  //Serial.println(msg);
  rf_driver.send((uint8_t *)msg,strlen(msg));
  rf_driver.waitPacketSent();
  delay(10);

}
